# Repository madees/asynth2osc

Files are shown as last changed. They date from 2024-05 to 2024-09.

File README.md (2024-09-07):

# Analog synthesizer to Open Sound Control (OSC) module

## Project description

Analog synth is coming back into hype among music artists. It has a strong culture of vintage, DIY, and customisation.

On the other hand, pro systems use digical control systems, such as DMX for lighting, or OpenSoundControl (OSC) for sound.

The idea for this project is to have a hardware to interface analog synth to advanced sound control systems.

This project is also designed to leverage the possibilities of open-source show control software [Chataigne](https://benjamin.kuperberg.fr/chataigne/).

There are a lot of solution to control an analog modular synthesizer from a computer, mainly by MIDI interfaces. But not so much options to do the opposite: control others FROM analog modulations. 
The features and purpose are very close to existing [Befaco VCMC](https://www.befaco.org/vcmc-2/), but with TCP-IP for OSC instead of serial for MIDI - so we need to upgrade the microcontroller.

Some inspiration for hardware can be found at open hardware synths from Mutable Instruments company. In its [repository](https://github.com/pichenettes/eurorack) we can find the exact reference design, typically for the [Yarns V3](https://pichenettes.github.io/mutable-instruments-documentation/modules/yarns/) MIDI digital interface.

## Glossary

### Musical Instrument Digital Interface (MIDI)
Communication protocol dedicated to music, used for communication between musical instruments and multimedia devices. Usually implemented as a serial connection, with a 5-pins DIN connector.

### OpenSoundControl (OSC)
Open, message-based protocol for communication between multimedia devices. Intended to be a next-generation replacement for MIDI.
[OSC specification 1.0 (Stanford University)](https://opensoundcontrol.stanford.edu/spec-1_0.html)
It is usually implemented on TCP-IP stack, most usually as UDP datagrams for real time applications.
It can be easily transmit thru Ethernet or Wifi at higher bit rate, and a much higher resolution of 32 bits float, than MIDI wich was based on 7 bits integer.

### CV - Control Voltages
The analog signals generated by the synthetisers are called CV.

### Gate and triggers
Other types of signals generated can be:
* Gate: a "digital" 0 and 1 signal, but with the synthesiser reference analog voltage,
* Trigger: a short-pulse "digital" 0 and 1 signal, to trigger a particular event.

### Chataigne
Chataigne is a user-friendly open-source show control software, allowing to connect several multimedia devices, hardware or software between them.
We develop belongside this hardware project asynth2osc a custom module for Chataigne, so this piece of software can be use easily to control anything from a real world analog modular, from sound to light, videos and activators of any kind.
[Chataigne source code on Github](https://github.com/benkuper/Chataigne)
[Artist-friendly Modular Machine for Art and Technology - Chataigne Official website](http://benjamin.kuperberg.fr/chataigne)

### Analog synthetizer
Synthetizer that uses analog circuits and signals to generate sound electronically.
[See the wikipedia page](https://en.wikipedia.org/wiki/Analog_synthesizer)

### Analog modular synthetizer
Modular synthesizers are composed of separate hardware modules for different functions. The modules can be connected together by the user to create a patch. The outputs from the modules may include audio signals, analog control voltages, or digital signals for logic or timing conditions.
[See the wikipedia page](https://en.wikipedia.org/wiki/Modular_synthesizer)

### VCV Rack
Open-source software that emulate analog modular synthetizers. Most of hardware modules are present. Especially, Tramasoft edited a module that is a kind of emulation of our asynth2osc module : cvOSCcv. This virtual module can be use to use real world analog hardware to control the software.
[VCV Rack cvOSCcv module page](https://library.vcvrack.com/trowaSoft/cvOSCcv)

### Eurorack
Standardized mechanical format for synthetizer, in a modular 3U rack. It usually fits in a "case" to ease musicians to build their own synthetizer, and have a unique Power Supply Unit and power busses for all the modules.

The dimensions are normalised :
* 3U = 128.5 mm height (U is professionnal standard 19" wide rack unit)
* 1HP = 5.08 mm, width is multiple of 1HP
* Depth should be <2.5mm or <4mm to be shallow

Exemple: Yarns is 12 HP and 3U, so front plate is 128.5x60.96mm. Its bottom PCB is tinier: 59x106,8mm, and has 3 screw holes to fit it to the front plate.

It uses 3.5mm jack for cabling, +/- 12V power supply on a 2x5p header connector, on the right lower corner of the board (facing the bottom).
Red side = -12V. Print a | on the board to indicate side. Don’t forget the protection circuit.

<!--
        +---------+
        |         |
 +12V   |  o   o  |  +12V
        |         |
 GND    |  o   o  |   GND
        |         |
 GND    |  o   o  |   GND
        |         |
 GND    |  o   o  |   GND
        |         |              |
 -12V   |  o   o  |  -12V        |
        |         |              |
        +---------+              |
                                 |
            ----                 |
                                 |
---------------------------------+
-->
Kroki generated Ditaa

## Benchmark
### Befaco VCMC specs (close features, MIDI only)
* Teensy 32 controller
    * NXP MK20DX256VLH7
    * 2x 16-bit ADC
    * 1x 12-bit DAC

* 8 CV muxed on 1 ADC

### Yarns V3 specs (close MCU, MIDI only)
* ST STM32F103CBT6 controller
    * 2x 12-bit ADC (16 channels)
    * 2x DAC
* External DAC DAC8564
    * 1x 16-bit DAC (4 channels)

## First architecture (RPI for Wifi, Bluetooth and cabled Ethernet support)
The first prototype includes:
* 8 analog inputs
* Rotary encoder and screen
* 4 digital inputs and 4 buttons for 8 interrupt inputs
* 1 analog audio output
* Pretty front panel with Eurorack format
* 5V power supply input

The BOM is:
* Raspberry Pi 3
* Pi-Plates DAQC2
* Adafruit I2C rotary encoder module, with click and LED #4991
* Adafruit quad-alphanumeric segmented display with I2C #1912
* 4 mini-arcade buttons with retro-lighting

### Pi-Plates DAQC2
This RPI hat is the GPIO interface, with a very good analog front end:
* Specs [here](https://pi-plates.com/daqc2r1/)

* SoC: Microchip PIC16F1517-I/PT
* 16x 10-bit ADC
* Analog input via TI SN74LV4051A 8:1 analog multiplexer
* Open Collector outputs via TI DS2003CM high-current Darlington driver and NXP 74HC 8-bit parallel-in/serial out shift register.

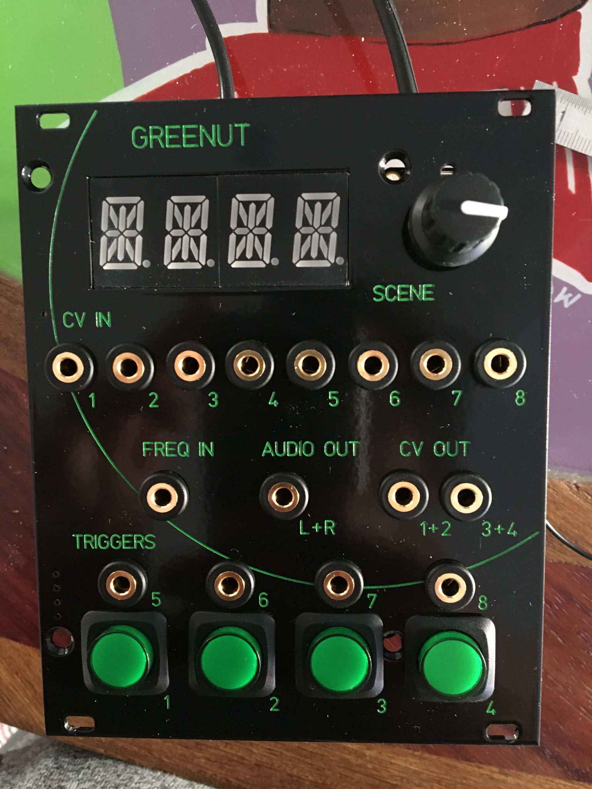
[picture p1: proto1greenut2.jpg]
proto1 front panel assembled

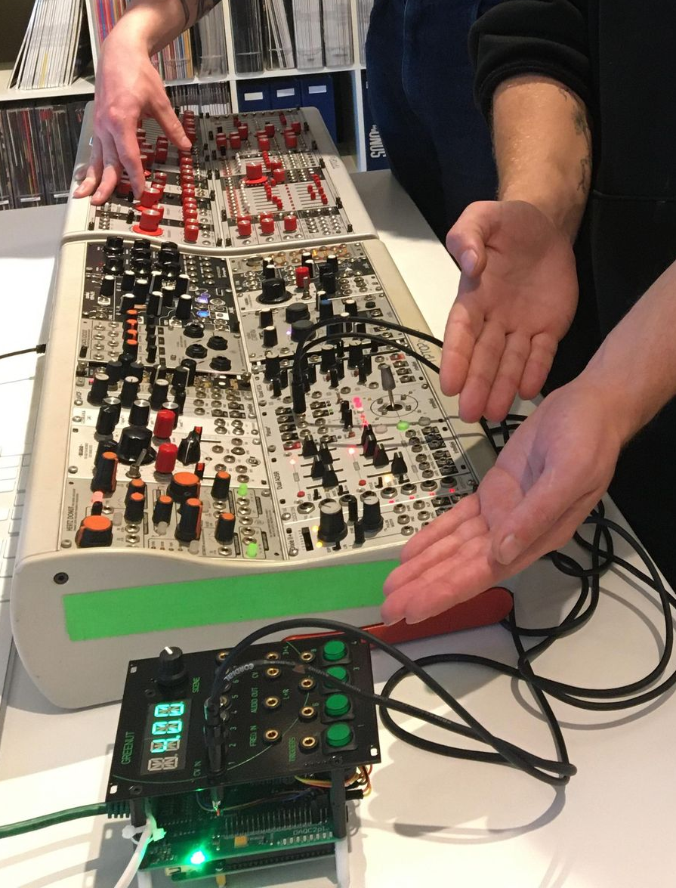
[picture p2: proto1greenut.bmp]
proto1 beta tests

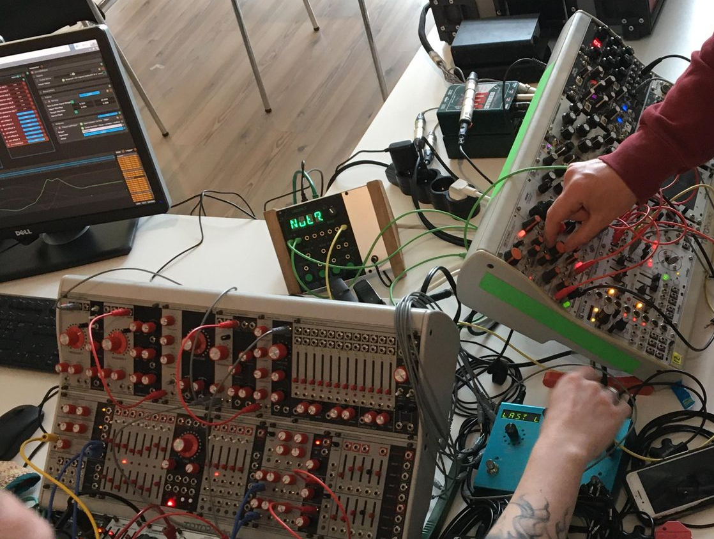
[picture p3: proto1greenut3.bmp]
proto1 beta tests


## Second architecture
This aims to integrate LEDs, buttons, and DACs on the same board to improve manufacturing and ralaibilty.
The Raspberry Pi is dropped and replaced by a custom board with WiFi/TCP-IP SoC and all the analog stuff.

It is possible to use a PCB board as front panel too, as a lot of synthesizer modules do.

For the software part, the board would only output the OSC.
I would consider implementing [TinyOSC](https://github.com/mhroth/tinyosc), a lightweight OSC implementation, preferably on Zephyr RTOS.

### Requirements
#### Ethernet
* Full TCP-IP stack implemented, with OSC other UDP protocol.
* DHCP, Link Local and Static IP settings.
* Wired RJ45, optionnal Wifi.

#### DAC
* This has to be the most crucial part for latency. Quick interface is preferable, like SPI.
* 8 channels input (audio stereo 3.5mm mini-jack).
* Minimum 16 bits, preferably 24.
* Sample rate: ideally at least 100Hz, application can be quite slow (LFO are around 2 Hz). Oversamplig is a must for smoothing and lower transmission rate.
* MCP3008 is an option.

#### Other IO
* MIDI input (also using stereo mini-jack).
Even if a lot of MIDI interface exist, and possibilties to send them other Ethernet with rtp-MIDI interfaces and protocol, forwarding some MIDI events to OSC would be a good feature. With options to set the kind of datas (Programm Changes, Note ON, Control Changes etc) to be tranmitted.

MIDI in uses an UART port, see the [Arduino tutorial](https://www.instructables.com/Send-and-Receive-MIDI-with-Arduino/).
or Yarns hardware 
Midi-jack pinout:

<!--
          | |
          +-+
NC 3  o           o  1  NC

Tip 5   o       o  4 Ring

            o
            2 Sleeve

          | |
          +-+
NC 3  o           o  1  NC

OUT- 5  o       o  4 OUT+

            o
            2 GND/Shield
-->
Kroki generated Ditaa

UART baud rate is 31250 kbps.

#### Power supply
Eurorack standard includes a +12/-12V power supply, but the currents are quite low, and sensitive to pollution. So we should rather use a 5V additional external power supply as an option.

#### Mechanical
It has to fit in Eurorack format. The smaller, the better,but no hard requirement for width.
Some work has to be done to fit the connectors, leds, buttons and mechanical parts nicely.

#### CV inputs

VC analog inputs can wiggle between several voltage ranges:
* -5V / 5V
* -12V / 12V
* 0 / 5V
* 0 / 12V

We need an input stage able to fit those input the 0 / 3.3V ADC microcontroller input.

Attenuators are specific modules used to reshape a specific CV.

The most used input is copied from Mutable Instruments and remaps a -5V / 5V input in a 0 / 3.3V output, but needs a -10V bias to handle those negatives.
In Befaco VCMC, an optional voltage gizmo converts 5V power supply to -12V / +12V for standalone behaviour.
We could also use an inverting circuit but it will... invert: -5V mapped to 3.3V and 5V mapped to 0V.

Voltages are clamped to 0-3.3V using Shottky diodes, but it should maybe signal saturation to the user somehow.

Better scaling:
* Several input scalers muxed?
* A fancy IC with digital control?
* Single scaler controlled by DAC output (hard)?
* 2-steps converter: rescaler (-12/12 to -5/5), scaler (-5/5 to 0/3).

#### Diagram
<!--
graph TD
  A[ ESP32 ] ==>| RMII | B[ Ethernet PHY ]
  A <==> | SPI | C[ NOR Flash ]
  A <==> | I2C | D[ GPIO expander ]
  T> MIDI in] ==> D
  D ==> | GPIO | E> LEDs ]
  F> Buttons ] ==> | GPIO | D
  G[ ADC ] ==> | SPI | A
  H[ Analog magic ] ==> | Analog | G
  I> 3.5 jacks ] ==> H
  B ==> J> RJ45 ]
  A ==> | DAC | M[ Analog out ]
  M ==> N> 3.5 jack ]
  M ==> O> PWM LED ]
  K> Power jack ] -.- | 12V | L[ DCDC ]
  L -.- | 3V3 | A
  A <==> | UART, JTAG | P[ FTDI ]
  P ==> Q> Debug USB ]
  Q -.- | 5V | L
  A === | U.FL | R[ Antenna ]
  A ==> | SPI | S> Display ]
-->

Kroki generated Mermaid

#### STM32 option
* Only performance range (STM32F7 and STM32H7) have RMII
* STM32H7 has 16-bits ADC, it's perfect

<!--
graph TD
  A[ STM32 ] ==>| RMII | B[ Ethernet PHY ]
  A <==> | SPI | C[ NOR Flash ]
  A <==> | GPIO | D> LEDs ]
  E> Buttons ] ==> | GPIO | A
  H[ Analog in ] ==> | ADC | A
  I> 3.5 jacks ] ==> H
  B ==> J> RJ45 ]
  A ==> | DAC | F[ Analog out ]
  F ==> N> 3.5 jack ]
  A ==> | PWM | O> PWM LED ]
  K> Power jack ] -.- | 12V | L[ DCDC ]
  L -.- | 3V3 | A
  A <==> | UART, JTAG | P> SWD header ]
  L -.- | 5V | G
  A ==> | SPI | S> Display ]
  T> 3.5 jack ] ==> U[ MIDI In ]
  U ==> | GPIO | A
  A <==> | USB | G> Debug USB ]
-->
Kroki generated Mermaid

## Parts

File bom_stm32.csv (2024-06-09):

Qty | Reference | Manufacturer | Type | Description |  | Price (unit) (€) | Equipped
1 | EC12E_SW | ALPS | Button | ALPS rotary Encoder EC12E series with switch | With output A/B | 1,53 | By hand
1 | PCB, 58x107mm, 2 layers | JLCPCB | PCB | Real board, at JLCPCB, by 5 |  | 7 | N.A.
1 | PCB, 80x107, 2 layers (same as 1) | JLCPCB | PCB | For front panel, by 5 |  | 7,24 | N.A.
1 | Resistors, capas, etc |  | Misc |  |  | 5 | PCBA
1 | CY8CMBR3110-SX2IT | Infineon | CI | 10 input capsense sensor |  | 2,71 | PCBA
1 | RJHSE5M80 | Amphenol | Connector | RJ45 jack |  | 1,37 | PCBA?
1 | 6N137SMT | Motorola | Misc | MOTOROLA OPTO COUPLER |  | 0,95 | PCBA
4 | D6R40F2LFS | C&K | Button | C&K D6R push button |  | 1,13 | By hand
10 | YLED0402Y | Yongyotai | LED | Yellow, 0402 | Min ordering qty: 50 | 0,01 | PCBA
1 | LM1117S-3.3 | HTC | LDO | 75dB@(120Hz) 1A Fixed 3.3V Positive electrode 12V SOT-223-3 Linear Voltage Regulators (LDO) | 12V OK, 800mA | 0,2 | PCBA
2 | W25Q32JVSSIQ | Windbond | IC | SPI Flash |  | 0,27 | PCBA
10 | PJ301WQP |  | Connector | Audio jack, 0.75$, 10.5mm depth, 3 pins | Can be found cheap on AliExpress | 0,75 | By hand
0 | MJ-3536N | CUI Devices | Connector | Normal audio jack, needs additionnal PCB and connector |  | 0,79 | By hand
1 | H1102NLT | Pulse Electronics |  | Ethernet transfo |  | 4,31 | PCBA
1 | LAN8742A-CZ-TR | Microchip | IC | RMII PHY |  | 1,92 | PCBA
0 | KMS-1102NL | Usakro |  | Ethernet transfo |  |  | PCBA
1 | STM32H723ZGT6 | ST | IC | 1MB 564KB FLASH 112 1.71V~3.6V 550MHz LQFP-144(20x20) |  | 10 | PCBA
0 | STM32H723VGT6 | ST | IC | 1MB 564KB FLASH 80 1.71V~3.6V 550MHz LQFP-100(14x14) |  | 10 | PCBA

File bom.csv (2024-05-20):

Qty | Reference | Manufacturer | Type | Description |  | Price (unit) (€) | Equipped | SoC bus
1 | EC12E_SW | ALPS | Button | ALPS rotary Encoder EC12E series with switch | With output A/B | 1,53 | By hand
1 | PCB, 58x107mm, 2 layers | JLCPCB | PCB | Real board, at JLCPCB, by 5 |  | 7 | N.A.
1 | PCB, 80x107, 2 layers (same as 1) | JLCPCB | PCB | For front panel, by 5 |  | 7,24 | N.A.
1 | Resistors, capas, etc |  | Misc |  |  | 5 | PCBA
0 | CY8CMBR3110-SX2IT | Infineon | CI | 10 input capsense sensor |  | 2,71 | PCBA
0 | RJHSE5M80 | Amphenol | Connector | RJ45 jack |  | 1,37 | PCBA?
10 | 6N137SMT | Motorola | Misc | MOTOROLA OPTO COUPLER |  | 0,95 | PCBA
4 | D6R40F2LFS | C&K | Button | C&K D6R push button |  | 1,13 | By hand | (GPIOx4)
10 | YLED0402Y | Yongyotai | LED | Yellow, 0402 | Min ordering qty: 50 | 0,01 | PCBA | (GPIOx10)
1 | LM1117S-3.3 | HTC | LDO | 75dB@(120Hz) 1A Fixed 3.3V Positive electrode 12V SOT-223-3 Linear Voltage Regulators (LDO) | 12V OK, 800mA | 0,2 | PCBA
1 | W25Q32JVSSIQ | Windbond | IC | SPI Flash |  | 0,27 | PCBA | SPI/QSPI
10 | PJ301WQP |  | Connector | Audio jack, 0.75$, 10.5mm depth, 3 pins | Can be found cheap on AliExpress | 0,75 | By hand
0 | MJ-3536N | CUI Devices | Connector | Normal audio jack, needs additionnal PCB and connector |  | 0,79 | By hand
1 | H1102NLT | Pulse Electronics |  | Ethernet transfo |  | 4,31
1 | XTEAWT-02-0000-00000LED1 | Wolfspeed | LED | White |  | 1,58 | PCBA | PWM
0 | PCM1808PWR | TI / China | ADC | Single-ended, analog-input 24-bit, 96-khz stereo | Not in Zephyr – cannot connect 4? | 0,45 | PCBA
1 | AD7606BSTZ | Analog Devices | ADC | 8-/6-/4-Channel DAS with 16-Bit, Bipolar Input, Simultaneous Sampling ADC | Not in Zephyr | 18 | PCBA | SPI/QSPI
0 | ADC128D818CIMT | TI | ADC | 12-Bit, 8-Channel, ADC System Monitor With Temperature Sensor, Internal – External Reference, and I2C Interface |  | 2,31 | PCBA
0 | 2041262-1 | TE Connectivity | Connector | Mini PCI-Express connector |  | 0,93 | N.A.
1 | Raspberry Pi 4 header footprint |  | Connector |  |  | 0 | N.A.
1 | ESP32-WROVER-IE-N8R8_C701351 | Espressif | SoC | ESP32-D0WDR2-V3, Ethernet possible, 8Mo RAM / 8Mo ROM |  | 4,5 | PCBA
4 | 74HC595D | NXP | Misc | 8-bit SHIFT REGISTER, output latch | For screen | 0,39 | By hand | SPI
0 | KINGBRIGHT-PDC54-11 | Kingbright | Screen | Kingbright PDC54-11GWA , also compatible with LITE-On LTP-3784G or Avago HDSP-A27C | 25.2 mm x 21.2 mm x 7.8 mm | 4,73 | By hand
1 | COM-21216 | SparkFun | Screen | 14-SEGMENT ALPHANUMERIC DISPLAY, blue | 12,80mm x 40,18mm x 7,00mm | 2,29 | By hand
1 | MAX7314ATG | Analog Device | IC | GPIO expander – 18 ports |  | 3,59 | PCBA | I2C
1 | FT2232HL-REEL | FTDI | IC | Serial programmer | Buy separate FTDI cables ? | 6,71 | PCBA | UART
1 | HX MICRO 5.9JB | Hanxia | Connector | 2A Female 5P 1 Micro-B USB | Debug supply and programmation | 0,5 | PCBA
1 | IP101GRI | IC+ | IC | Ethernet PHY |  | 0,8 | PCBA | RMII
1 | "1461530050" | Molex | Antenna | U.FL adhesive 2.4GHz antenna | Verify connector and freq | 2,17 | By hand
0 | TLA2528 | TI | IC | Small, 8-Channel, 12-Bit ADC With I2C Interface and GPIOs | The TLA2528 communicates via an I2C-compatible interface and supports standard-mode (100 kHz) fast-mode (400 kHz), fast-mode plus (1 MHz), and high-speed mode (3.4 MH | 4,42 | PCBA
0 | MCP3008-I/SL | Microchip | IC | 10Bit 2.7V~5.5V 200kHz SPI SOIC-16 Analog To Digital Converters (ADCs) | Not enough res? | 5,6 | PCBA
0 | LP2019ANL | Link-PP |  | Single Port 10/100 BASE-T Ethernet Transformer lan Magnetics POE+ 350mA 16 Pin |  | 0,67

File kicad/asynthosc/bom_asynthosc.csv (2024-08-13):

Reference | Value | Datasheet | Footprint | Qty | DNP | RefNum | Manufacturer
U8,U9 | MCP6004 | http://ww1.microchip.com/downloads/en/DeviceDoc/21733j.pdf | Package_SO:TSSOP-14_4.4x5mm_P0.65mm | 2 |  | MCP6004T-E/ST | Microchip
Q1,Q2 | Q_NPN_BEC | ~ | Package_TO_SOT_SMD:SOT-23 | 2 |  | S8050-J3Y | JSMSEMI
U6 | STM32F723VETx | https://www.st.com/resource/en/datasheet/stm32f723ve.pdf | Package_QFP:LQFP-100_14x14mm_P0.5mm | 1 |  | STM32H723VGT6 | STMicroelectronics
D15 | 1N4148WT | https://www.diodes.com/assets/Datasheets/ds30396.pdf | Diode_SMD:D_SOD-523 | 1 |  | 1N4148WT | LGE
D9,D10,D11,D12,D13,D14,D16,D17 | D_Schottky_1N5817 | ~ | Diode_SMD:D_SOD-123 | 8 |  | 1N5817
D2 | 1N5819WS | https://datasheet.lcsc.com/lcsc/2204281430_Guangdong-Hottech-1N5819WS_C191023.pdf | Diode_SMD:D_SOD-323 | 1 |  | 1N5819WS | Guangdong
SW1 | SW_Push | ~ | Button_Switch_SMD:SW_SPST_B3S-1000 | 1 | DNP | 6.0*6.0*6.0 | Boomele
FB1,FB2,FB3 | BLM15PX330SN1D | ~ | Inductor_SMD:L_0402_1005Metric | 3 |  | BLM15PX330SN1D | Murata
SW8 | RotaryEncoder | ~ | Rotary_Encoder:RotaryEncoder_Alps_EC12E_Vertical_H20mm | 1 |  | EC11E18244AU | Alps
D1,D3 | ESD9B5.0ST5G | https://www.onsemi.com/pub/Collateral/ESD9B-D.PDF | Diode_SMD:D_SOD-923 | 2 |  | ESD9B5.0ST5G | OnSemi
DS1 | OLED Connector 128x64 | https://www.jx-wisevision.com/1-54-small-128x64-dots-oled-display-module-screen-product/ | asynthosc:HRO_FPC0.5B-WTG-24P_1x24-1MP_P0.5mm_Horizontal | 1 |  | FPC0.5B-WTG-24P | HRO Parts
U12 | H11L1 | https://www.onsemi.com/pub/Collateral/H11L3M-D.PDF | Package_DIP:SMDIP-6_W9.53mm | 1 |  | H11L1SM | OnSemi
J12 | RJ45_LED_Shielded | ~ | asynthosc:RJ45_HCTL_HC-RJ45-053-2 | 1 |  | HC-RJ45-053-2 | HCTL
U10 | LAN8742A | http://ww1.microchip.com/downloads/en/DeviceDoc/8742a.pdf | Package_DFN_QFN:VQFN-24-1EP_4x4mm_P0.5mm_EP2.5x2.5mm_ThermalVias | 1 |  | LAN8742A | Microchip
U1 | LM1117S-3.3 | http://www.ti.com/lit/ds/symlink/lm1117.pdf | Package_TO_SOT_SMD:SOT-223 | 1 |  | LM1117S-3.3 | HTC Korea
U4 | LM1117S-5.0 | http://www.ti.com/lit/ds/symlink/lm1117.pdf | Package_TO_SOT_SMD:SOT-223 | 1 |  | LM1117S-5.0 | HTC Korea
U2 | LMR62421XMF | http://www.ti.com/lit/ds/symlink/lmr62421.pdf | Package_TO_SOT_SMD:SOT-23-5 | 1 |  | LMR62421XMF | TI
J1 | USB_B_Micro | ~ | asynthosc:USB_Micro-B_Shou-han-MicroXNJ | 1 |  | MicroXNJ | ShouHan
Y1 | 8MHz, 8pF | ~ | asynthosc:Crystal_SMD_3225-2Pin_3.2x2.5mm | 1 |  | NX3225GD-8MHZ-STD-CRA-3 | NDK
J6,J7,J8,J9,J10,J11,J13,J14 | AudioJack3 | ~ | asynthosc:Jack_3.5mm_3legs_XKB_PJ-3411_Vertical | 8 |  | PJ-3411 | XKB
TR1 | PT61017PEL | https://www.bourns.com/docs/Product-Datasheets/PT61017PEL.pdf | Transformer_SMD:Transformer_Ethernet_Bourns_PT61017PEL | 1 |  | PT61017PEL
C3,C5,C12,C45 | 10uF | ~ | Capacitor_SMD:CP_Elec_4x5.4 | 4 |  | RVT1V100M0405 | Roqang
U5 | Si1869DH | https://mm.digikey.com/Volume0/opasdata/d220001/medias/docus/1171/SI1869DH.pdf | Package_TO_SOT_SMD:SOT-363_SC-70-6 | 1 |  | Si1869DH
D4,D5,D6 | SS24 | https://www.vishay.com/docs/88748/ss22.pdf | Diode_SMD:D_SMA | 3 |  | SS24 | Fosan
SW2,SW6,SW9,SW10 | SW_MEC_5G_LED | http://www.apem.com/int/index.php?controller=attachment&id_attachment=488 | asynthosc:TPB01-X0XLXX_SW_MEC_5G | 4 |  | TPB01-3016L6W | ROCPU
U11 | USBLC6-2P6 | https://www.st.com/resource/en/datasheet/usblc6-2.pdf | Package_TO_SOT_SMD:SOT-666 | 1 |  | USBLC6-2P6 | STMicroelectronics
U3 | USBLC6-2SC6 | https://www.st.com/resource/en/datasheet/usblc6-2.pdf | Package_TO_SOT_SMD:SOT-23-6 | 1 |  | USBLC6-2SC6 | STMicroelectronics
U7 | W25Q32JVSS | http://www.winbond.com/resource-files/w25q32jv%20revg%2003272018%20plus.pdf | Package_SO:SOIC-8_5.23x5.23mm_P1.27mm | 1 |  | W25Q32JVSS | Winbond
DS1_S1 | OLED Display 128x64 | ~ | Display:OLED-128O064D | 1 | DNP | X154-2864KSWBG01-C24 | NewVisio
Y2 | 25MHZ,20PF,30PPM | ~ | Crystal:Crystal_SMD_3225-4Pin_3.2x2.5mm | 1 |  | X322525MOB4SI | YXC
L1 | 8.2uH / 80mOhm | https://www.lcsc.com/datasheet/lcsc_datasheet_2307121520_XR-XRCD75-8R2M_C7462918.pdf | asynthosc:L_XR_XRCD75-XRX_7x7.8 | 1 |  | XRCD75-8R2M | Xiangru
SW3,SW4,SW5,SW7 | r=1M | ~ |  | 4

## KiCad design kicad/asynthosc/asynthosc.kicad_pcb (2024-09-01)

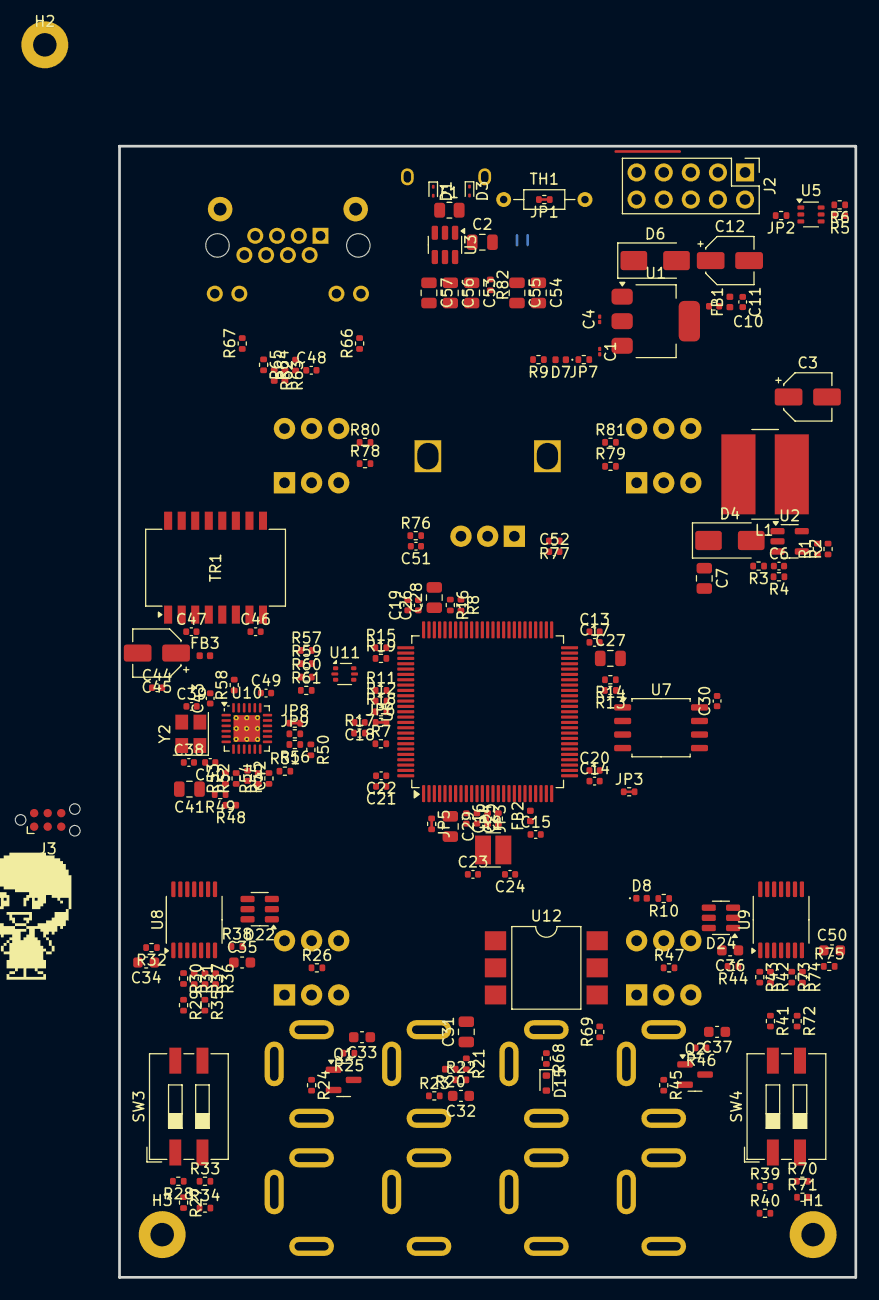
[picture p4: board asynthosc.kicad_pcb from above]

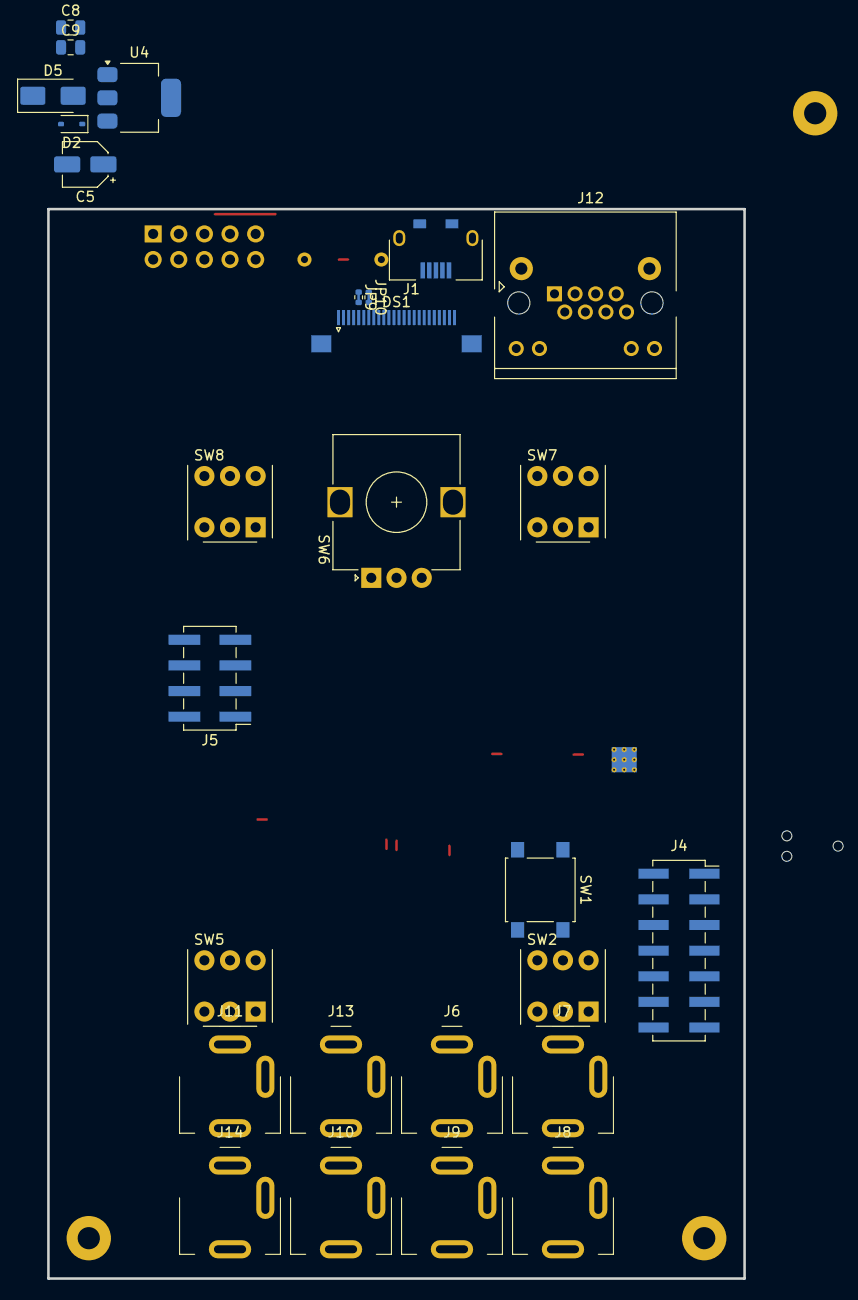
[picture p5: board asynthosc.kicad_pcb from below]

Board: 4 copper layers, 69.0 x 106.0 mm, 211 parts (27 on the bottom side), 144 nets, no tracks yet.

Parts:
C1, C4: 100nF; C_01005_0402Metric
C2, C8, C9: 100nF; C_0805_2012Metric
C3, C5, C12, C45: 10uF; CP_Elec_4x5.4
C6: 680pF; C_0402_1005Metric
C7: 47uF / 3.037mOhms; C_0805_2012Metric
C10: 10nF; C_0402_1005Metric
C11, C13, C14, C15, C16, C17, C18, C19, C20, C21, C22, C25, C26, C30, C42, C43, C44, C46, C47, C49, C51, C52: 100nF; C_0402_1005Metric
C23, C24: 4.3pF; C_0402_1005Metric
C27, C28: 2.2u X7R; C_0805_2012Metric
C29, C41: 1uF; C_0805_2012Metric
C31: 10uF; C_0805_2012Metric
C32: 18pF; C_0603_1608Metric
C33, C37: 100nF; C_0603_1608Metric
C34, C35, C36, C50: 1nF; C_0603_1608Metric
C38, C39: 30pF; C_0402_1005Metric
C40: 470pF; C_0402_1005Metric
C48: 1000pF X7R; C_0402_1005Metric
C53: 2.2uF/25V; C_0805_2012Metric
C54, C55: 1uF / 16V; C_0805_2012Metric
C56: 4.7uF/25V/X7R; C_0805_2012Metric
C57: 0.1uF/25V/X7R; C_0805_2012Metric
D1, D3: ESD9B5.0ST5G; D_SOD-923
D2: 1N5819WS; D_SOD-323
D4, D5, D6: SS24; D_SMA
D7, D8: LED; LED_0402_1005Metric
D15: 1N4148WT; D_SOD-523
D22, D24: D_Schottky_Dual_SD103ASDM; SOT-23-6
DS1: OLED Connector 128x64; HRO_FPC0.5B-WTG-24P_1x24-1MP_P0.5mm_Horizontal
F1: Fuse, 1.25A, trip 2.5A; R_0805_2012Metric
FB1, FB2, FB3: BLM15PX330SN1D; L_0402_1005Metric
H1, H2, H3: MountingHole_Pad; MountingHole_2.2mm_M2_Pad
J1: USB_B_Micro; USB_Micro-B_Shou-han-MicroXNJ
J2: Conn_02x05_Odd_Even; PinHeader_2x05_P2.54mm_Vertical
J3: Conn_ARM_SWD_TagConnect_TC2030-NL; Tag-Connect_TC2030-IDC-NL_2x03_P1.27mm_Vertical
J4: Conn_02x07_Odd_Even; PinSocket_2x07_P2.54mm_Vertical_SMD
J5: Conn_02x04_Odd_Even; PinHeader_2x04_P2.54mm_Vertical_SMD
J6, J7, J8, J9, J10, J11, J13, J14: AudioJack3; Jack_3.5mm_3legs_XKB_PJ-3411_Vertical
J12: RJ45_LED_Shielded; RJ45_HCTL_HC-RJ45-053-2
JP1, JP3, JP3#2, JP4, JP5, JP6, JP8, JP9#2, JP10: SolderJumper_2_Bridged; SolderJumper_0402_1005Metric_Bridged
JP2, JP7, JP9: SolderJumper_2_Open; R_0402_1005Metric
L1: 8.2uH / 80mOhm; L_XR_XRCD75-XRX_7x7.8
Q1, Q2: Q_NPN_BEC; SOT-23
R1, R2, R3, R5, R6, R8, R25, R46, R76, R77, R78, R79: 10k; R_0402_1005Metric
R4: 69.8k; R_0402_1005Metric
R7, R24, R29, R30, R35, R36, R41, R42, R45, R48, R49, R50, R72, R73: 100k; R_0402_1005Metric
R9, R10, R26, R47, R66, R67, R80, R81: 270R; R_0402_1005Metric
R11, R12, R13, R14, R15, R16, R17, R18, R19: 22R; R_0402_1005Metric
R20, R22: 39k; R_0402_1005Metric
R21: 5.6k; R_0402_1005Metric
R23: 1k; R_0402_1005Metric
R27, R33, R39, R70: 47k; R_0402_1005Metric
R28, R31, R32, R34, R37, R38, R40, R43, R44, R71, R74, R75: 33k; R_0402_1005Metric
R51: 1.5K; R_0402_1005Metric
R52, R53, R54, R55, R56: 33R; R_0402_1005Metric
R57, R59, R60, R61: 50R; R_0402_1005Metric
R58: 12.1k; R_0402_1005Metric
R62, R63, R64, R65: 75R; R_0402_1005Metric
R68, R69: 220; R_0402_1005Metric
R82: 1M; R_0402_1005Metric
SW1: SW_Push; SW_SPST_B3S-1000
SW2, SW5, SW7, SW8: SW_MEC_5G_LED; TPB01-X0XLXX_SW_MEC_5G
SW3, SW4: SW_DIP_x02; SW_DIP_SPSTx02_Slide_9.78x7.26mm_W8.61mm_P2.54mm
SW6: RotaryEncoder; RotaryEncoder_Alps_EC12E_Vertical_H20mm
TH1: Thermistor_NTC; R_Axial_DIN0204_L3.6mm_D1.6mm_P7.62mm_Horizontal
TR1: PT61017PEL; Transformer_Ethernet_Bourns_PT61017PEL
U1: LM1117S-3.3; SOT-223
U2: LMR62421XMF; SOT-23-5
U3: USBLC6-2SC6; SOT-23-6
U4: LM1117S-5.0; SOT-223
U5: Si1869DH; SOT-363_SC-70-6
U6: STM32F723VETx; LQFP-100_14x14mm_P0.5mm
U7: W25Q32JVSS; SOIC-8_5.23x5.23mm_P1.27mm
U8, U9: MCP6004; TSSOP-14_4.4x5mm_P0.65mm
U10: LAN8742A; VQFN-24-1EP_4x4mm_P0.5mm_EP2.5x2.5mm_ThermalVias
U11: USBLC6-2P6; SOT-666
U12: H11L1; SMDIP-6_W9.53mm
Y1: 8MHz, 8pF; Crystal_SMD_3225-2Pin_3.2x2.5mm
Y2: 25MHZ,20PF,30PPM; Crystal_SMD_3225-4Pin_3.2x2.5mm

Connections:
3V3: C4.1, C13.1, C14.1, C15.1, C16.1, C17.1, C19.1, C20.1, C21.1, C22.1, C25.1, C26.1, C30.1, C40.1, C41.1, C42.1, C54.1, C55.1, D22.2 (K), D22.5 (K), D24.2 (K), D24.5 (K), DS1.5 (VDD), FB2.1, FB3.2, J3.1 (VCC), J4.2, JP5.2 (B), R9.1, R10.1, R25.2, R46.2, R48.2, R49.2, R50.2, R51.2, R69.1, R76.1, R77.1, R78.1, R79.1, R80.1, R81.1, U1.2 (VO), U6.11 (VDD), U6.27 (VDD), U6.50 (VDD), U6.75 (VDD), U6.100 (VDD), U7.8 (VCC), U10.6 (VDDCR), U10.9 (VDDIO), U12.6
3V3_FILT: C43.1, C44.1, C45.1, C46.1, C47.1, C49.1, FB3.1, R57.2, R59.2, R60.2, R61.2, TR1.2 (C_TD), TR1.7 (C_RD), U10.1 (VDD2A), U10.19 (VDD1A), U11.5 (VBUS)
5V: C1.1, D5.1 (K), D6.1 (K), R30.2, R36.2, R42.2, R73.2, U1.3 (VI), U8.4 (V+), U9.4 (V+)
+10V: C6.2, C7.1, C56.1, C57.1, D4.1 (K), DS1.23 (VCC), JP2.2 (B), R4.1
/Analog_in/CVIN0: C34.1, D22.6 (common), R32.1, U6.22 (PA0), U8.1
/Analog_in/CVIN1: C35.1, D22.3 (common), R38.1, U6.25 (PA3), U8.7
/Analog_in/CVIN2: C36.1, D24.6 (common), R44.1, U6.29 (PA5), U9.1
/Analog_in/CVIN3: C50.1, D24.3 (common), R75.1, U6.30 (PA6), U9.7
/Analog_in/TRG0: C37.2, Q2.3 (C), R46.1, SW5.1, SW5.3 (K)
/Analog_in/TRG1: C33.2, Q1.3 (C), R25.1, SW2.1, SW2.3 (K), U6.43 (PE13)
/Interface/BTN_1: R78.2, SW7.1
/Interface/BTN_2: R79.2, SW8.1
/Interface/ROT_A: C52.1, R77.2, SW6.A
/Interface/ROT_B: C51.1, R76.2, SW6.B
/Interface/SCLK: DS1.13 (D0), U6.78 (PC10)
/Interface/SDIN: DS1.14 (D1), U6.80 (PC12)
/Midi_in/MIDI_IN+: J13.R, R68.1
/Midi_in/MIDI_IN-: D15.2 (A), J13.T, U12.2
/Midi_in/MIDI_TO_SOC: R69.2, U12.4
/Soc/BOOT0: R7.2, U6.94 (BOOT0)
/Soc/DAC_OUT1: C31.2, U6.28 (PA4)
/Soc/DISP_10V_EN: R1.1, R2.1, U2.4 (EN)
/Soc/Ethernet/RJ45_LED1: J12.12, U10.3 (LED1/REGOFF)
/Soc/Ethernet/RJ45_LED2: J12.10, U10.2 (LED2/~INTSEL)
/Soc/Ethernet/RJ_RX_N: J12.6, R62.2, TR1.15 (C_TX)
/Soc/Ethernet/RJ_RX_P: J12.3, TR1.14 (TX-)
/Soc/Ethernet/RJ_TX_N: J12.2, TR1.11 (RX+)
/Soc/Ethernet/RJ_TX_P: J12.1, TR1.9 (RX-)
/Soc/Ethernet/RX_N: R57.1, TR1.1 (TD+), U10.22 (RXN), U11.6 (I/O1)
/Soc/Ethernet/RX_P: R59.1, TR1.3 (TD-), U10.23 (RXP), U11.1 (I/O1)
/Soc/Ethernet/TX_N: R60.1, TR1.6 (RD+), U10.20 (TXN), U11.4 (I/O2)
/Soc/Ethernet/TX_P: R61.1, TR1.8 (RD-), U10.21 (TXP), U11.3 (I/O2)
/Soc/JTCK: R15.2, U6.76 (PA14)
/Soc/JTCK_CONN: J3.4 (SWCLK), J4.4, R15.1
/Soc/JTDI: R19.2, U6.77 (PA15)
/Soc/JTDI_CONN: J4.14, R19.1
/Soc/JTDO: R18.2, U6.89 (PB3)
/Soc/JTDO_CONN: J3.6 (SWO), J4.12, R18.1
/Soc/JTMS: R16.2, U6.72 (PA13)
/Soc/JTMS_CONN: J3.2 (SWDIO), J4.8, R16.1
/Soc/NRST: C18.1, JP6.1 (A), JP8.2 (B), R17.2, SW1.2, U6.14 (NRST)
/Soc/NRST_CONN: J3.3 (~RESET), J4.10, R17.1
/Soc/QSPI_BK2_IO0: U6.18 (PC3), U7.5 (DI(IO0))
/Soc/QSPI_BK2_IO1: U6.34 (PB0), U7.2 (DO(IO1))
/Soc/QSPI_BK2_IO2: U6.1 (PE2), U7.3 (IO2)
/Soc/QSPI_BK2_IO3: U6.60 (PD13), U7.7 (IO3)
/Soc/QSPI_BK2_NCS: U6.41 (PE11), U7.1 (~CS)
/Soc/QSPI_CLK: U6.36 (PB2), U7.6 (CLK)
/Soc/RMII_CRS_DV: R55.1, U6.31 (PA7)
/Soc/RMII_MDC: U6.16 (PC1), U10.13 (MDC)
/Soc/RMII_MDIO: R51.1, U6.24 (PA2), U10.12 (MDIO)
/Soc/RMII_REF_CLK: R50.1, R56.1, U6.23 (PA1)
/Soc/RMII_RXD0: R48.1, R52.1, U6.32 (PC4)
/Soc/RMII_RXD1: R49.1, R53.1, U6.33 (PC5)
/Soc/RMII_TXD0: U6.51 (PB12), U10.17 (TXD0)
/Soc/RMII_TXD1: U6.52 (PB13), U10.18 (TXD1)
/Soc/RMII_TX_EN: R14.2, U6.47 (PB11), U10.16 (TXEN)
/Soc/USART2_DBG_RX: R11.2, U6.87 (PD6)
/Soc/USART2_DBG_TX: R12.2, U6.86 (PD5)
/Soc/USART3_BOOT_DBG_TX: R13.2, U6.46 (PB10)
/Soc/USB_D_N: U3.4 (I/O2), U6.70 (PA11)
/Soc/USB_D_P: U3.6 (I/O1), U6.71 (PA12)
/Soc/USB_ID: D3.2 (A2), J1.4 (ID), U6.69 (PA10)
/Soc/VDDA: FB2.2, U6.20 (VREF+), U6.21 (VDDA)
/Supply/5V_CLEAN: C11.1, C12.1, D6.2 (A), FB1.2
/Supply/5V_EUR: C9.1, D5.2 (A), U4.2 (VO)
/Supply/DISP_12V_EN: R5.2, U5.5 (ON)
/Supply/EUR_+12V: D2.2 (A), J2.1, J2.2
/Supply/EUR_-12V: J2.9, J2.10
/Supply/IN_+12V: C5.1, C8.1, D2.1 (K), R6.1, U4.3 (VI), U5.4 (IN)
/Supply/USBIN_D_N: J1.2 (D-), U3.3 (I/O2)
/Supply/USBIN_D_P: J1.3 (D+), U3.1 (I/O1)
/Supply/VBUS: C2.1, C3.1, D1.2 (A2), F1.1, J1.1 (VBUS), L1.1, R1.2, R8.1, U2.5 (VIN), U3.5 (VBUS)
GND: C1.2, C2.2, C3.2, C4.2, C5.2, C7.2, C8.2, C9.2, C10.2, C11.2, C12.2, C13.2, C14.2, C15.2, C16.2, C17.2, C18.2, C19.2, C20.2, C21.2, C22.2, C23.1, C24.1, C25.2, C26.2, C27.2, C28.2, C29.2, C30.2, C33.1, C37.1, C38.1, C39.1, C40.2, C41.2, C42.2, C43.2, C44.2, C45.2, C46.2, C47.2, C48.2, C49.2, C51.2, C52.2, C53.2, C54.2, C55.2, C56.2, C57.2, D1.1 (A1), D3.1 (A1), D22.1 (A), D22.4 (A), D24.1 (A), D24.4 (A), DS1.1 (GND), DS1.2 (VLSS), DS1.3 (VSS), DS1.11 (R/~W), DS1.12 (E/~RD), DS1.16 (D3), DS1.17 (D4), DS1.18 (D5), DS1.19 (D6), DS1.20 (D7), DS1.24 (GND), H1.1, H2.1, H3.1, J1.5 (GND), J1.6 (Shield), J2.3, J2.4, J2.5, J2.6, J2.7, J2.8, J3.5 (GND), J4.1, J4.3, J4.5, J4.6, J4.7, J4.9, J4.11, J4.13, J5.4, J5.5, J6.S, J7.S, J8.S, J9.S, J10.S, J11.S, J12.SH, J14.S, JP3#2.2 (B), JP7.1 (A), JP9#2.1 (A), JP10.1 (A), Q1.2 (E), Q2.2 (E), R2.2, R3.2, R5.1, R7.1, R20.2, R26.2, R28.2, R31.2, R34.2, R37.2, R40.2, R43.2, R47.2, R54.1, R58.2, R66.1, R67.1, R71.2, R74.2, R82.2, SW1.1, SW2.4 (A), SW5.4 (A), SW6.C, SW7.4 (A), SW8.4 (A), U1.1 (GND), U2.2 (GND), U3.2 (GND), U4.1 (GND), U5.1 (R2), U6.10 (VSS), U6.19 (VSSA), U6.26 (VSS), U6.49 (VSS), U6.74 (VSS), U6.99 (VSS), U7.4 (GND), U8.9 (-), U8.11 (V-), U9.11 (V-), U10.25 (VSS), U11.2 (GND), U12.5
unnamed: C31.1, R20.1, R21.2
unnamed: C32.2, R22.1, R23.2, U8.8
unnamed: C48.1, R62.1, R63.1, R64.1, R65.1
unnamed: D4.2 (A), L1.2, U2.1 (SW)
unnamed: D7.2 (A), R9.2
unnamed: D7.1 (K), JP7.2 (B)
unnamed: D8.2 (A), R10.2
unnamed: D15.1 (K), R68.2, U12.1
unnamed: DS1.6 (BS1), JP9#2.2 (B)
unnamed: DS1.7 (BS2), JP10.2 (B)
unnamed: DS1.21 (IREF), R82.1
unnamed: C53.1, DS1.22 (VCOMH)
unnamed: J5.1, R11.1
unnamed: J5.2, R13.1
unnamed: J5.7, R12.1
unnamed: J5.8, R14.1
unnamed: J6.T, R23.1
unnamed: J7.T, R24.2
unnamed: J8.T, R27.2, SW3.1
unnamed: J10.T, R39.2, SW4.1
unnamed: J11.T, R45.2
unnamed: J12.4, J12.5, R64.2
unnamed: J12.7, J12.8, R65.2
unnamed: J12.9, R66.2
unnamed: J12.11, R67.2
unnamed: F1.2, JP1.1 (A), TH1.1
unnamed: C10.1, FB1.1, JP1.2 (B), TH1.2
unnamed: JP2.1 (A), U5.2 (OUT), U5.3 (OUT)
unnamed: JP3.1 (A), U6.12 (PH0)
unnamed: C23.2, JP3.2 (B), Y1.2
unnamed: JP4.1 (A), U6.13 (PH1)
unnamed: C24.2, JP4.2 (B), Y1.1
unnamed: C29.1, JP5.1 (A), U6.6 (VBAT)
unnamed: JP6.2 (B), U6.90 (PB4)
unnamed: JP8.1 (A), U10.15 (~RST)
unnamed: Q1.1 (B), R24.1
unnamed: Q2.1 (B), R45.1
unnamed: R26.1, SW2.2
unnamed: R47.1, SW5.2
unnamed: R27.1, R28.1, R29.2, SW3.4 (2)
unnamed: J9.T, R33.2, SW3.2 (1)
unnamed: R33.1, R34.1, R35.2, SW3.3 (2)
unnamed: R39.1, R40.1, R41.2, SW4.4 (2)
unnamed: J14.T, R70.2, SW4.2 (1)
unnamed: R70.1, R71.1, R72.2, SW4.3 (2)
unnamed: R80.2, SW7.3 (K)
unnamed: R81.2, SW8.3 (K)
unnamed: R63.2, TR1.10 (C_RX)
unnamed: C6.1, R3.1, R4.2, U2.3 (FB)
unnamed: R6.2, U5.6 (R1)
unnamed: R8.2, U6.68 (PA9)
unnamed: C27.1, U6.48 (VCAP_1)
unnamed: C28.1, U6.73 (VCAP_2)
unnamed: R30.1, R31.1, U8.3 (+)
unnamed: C34.2, R29.1, R32.2, U8.2 (-)
unnamed: R36.1, R37.1, U8.5 (+)
unnamed: C35.2, R35.1, R38.2, U8.6 (-)
unnamed: C32.1, R21.1, R22.2, U8.10 (+)
unnamed: R42.1, R43.1, U9.3 (+)
unnamed: C36.2, R41.1, R44.2, U9.2 (-)
unnamed: R73.1, R74.1, U9.5 (+)
unnamed: C50.2, R72.1, R75.2, U9.6 (-)
unnamed: R55.2, U10.11 (CRS_DV/MODE2)
unnamed: R58.1, U10.24 (RBIAS)
unnamed: R52.2, U10.8 (RXD0/MODE0)
unnamed: R53.2, U10.7 (RXD1/MODE1)
unnamed: R54.2, U10.10 (RXER/PHYAD0)
unnamed: C38.2, U10.5 (XTAL1/CLKIN), Y2.1
unnamed: C39.2, U10.4 (XTAL2), Y2.2
unnamed: R56.2, U10.14 (~INT/REFCLKO)

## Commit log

2024-01-23 doc: adding a draft bom
    [bom.csv]
2024-05-05 wip: update bom and description
    [bom.csv]
2024-05-05 add ldo
    [bom.csv]
2024-05-20 wip: STM32 architecture option
2024-05-20 wip: esp32 bom update
    [bom.csv]
2024-05-20 bom stm32
    [bom_stm32.csv]
2024-05-21 doc: add dac comparison, fix architecture drawing with stm32
2024-06-09 bom: optional 100-pins stm32
    [bom_stm32.csv]
2024-08-02 sch: add kicad files
    [analog_in.kicad_sch, asynthosc.kicad_pcb, asynthosc.kicad_sch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]
2024-08-02 sch: wip, add .gitignore
    [analog_in.kicad_sch, misc.kicad_sch, soc.kicad_sch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]
2024-08-06 sch: wip
    [CVin.kicad_sch, Int_in.kicad_sch, Trig_in.kicad_sch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]
2024-08-06 sch: basic stm32 with power, clocks and debug
    [ethernet.kicad_sch, soc.kicad_sch, supply.kicad_sch]
2024-08-06 sch: rmii side
    [asynthosc.kicad_sch, bom_asynthosc.csv, ethernet.kicad_sch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]
2024-08-07 sch: top sheet pins input
    [asynthosc.kicad_sch, soc.kicad_sch]
2024-08-08 sch: update and new interface sheet
    [analog_in.kicad_sch, asynthosc.kicad_sch, ethernet.kicad_sch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]
2024-08-08 comp: add jack footprints
2024-08-09 sch: add spi nor, display connection, and more footprints
    [CVin.kicad_sch, Int_in.kicad_sch, analog_in.kicad_sch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]
2024-08-09 sch: power supply improvements
    [asynthosc.kicad_sch, soc.kicad_sch, supply.kicad_sch]
2024-08-09 sch: update footprint links
    [CVin.kicad_sch, Int_in.kicad_sch, analog_in.kicad_sch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]
2024-08-13 sch: change stm32 for smaller one, create smaller jumper footprint
    [CVin.kicad_sch, Int_in.kicad_sch, analog_in.kicad_sch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]
2024-08-13 bom: update bom for lcsc
    [CVin.kicad_sch, Int_in.kicad_sch, analog_in.kicad_sch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]
2024-08-13 sch: dip switch with separated sym
    [CVin.kicad_sch, asynthosc.kicad_pcb]
2024-08-13 [sch][brd] Fix RJ45 footprint
    [asynthosc.kicad_pcb]
2024-08-13 brd: move connectors to bot (components will be on bottom, connectors on top)
    [asynthosc.kicad_pcb]
2024-09-01 pcb: placing
    [asynthosc.kicad_pcb, asynthosc.kicad_sch, soc.kicad_sch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]
2024-09-01 pcb: place and change some components for easier routing
    [CVin.kicad_sch, Int_in.kicad_sch, analog_in.kicad_sch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]

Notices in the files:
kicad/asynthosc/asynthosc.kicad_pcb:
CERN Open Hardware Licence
